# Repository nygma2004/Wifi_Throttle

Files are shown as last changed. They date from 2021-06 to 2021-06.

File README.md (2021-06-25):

# Wifi Throttle
This project is created for my Wifi LokRemote project (https://github.com/nygma2004/Wifi_LokRemote) so I can control my locos using a physical control as opposed to a mobile phone. This project contains a ESP32 Wifi microcontroller which is communicating with the Wifi LokRemote over wifi sending direction, speed, light and sound commands over UDP messages.

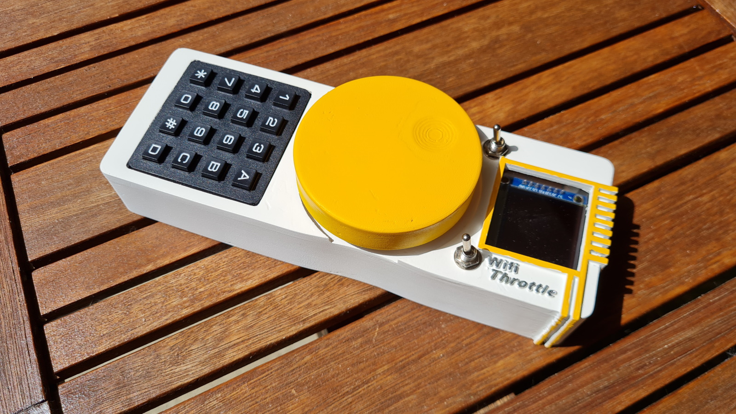
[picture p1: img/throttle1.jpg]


You can also check out my video on how I am using this trhottle for my 7 1/4" gauge ride-on-loco:
Prototype (https://www.youtube.com/watch?v=79uQtgcNUlQ)

Also check the project for the main "receiver" here: https://github.com/nygma2004/Wifi_LokRemote

## Main Features
- Connects to the Wifi network (AP) generated by the LokRemote controller to control the loco from a physical throttle
- Power supply is from a separate 5V power source via the USB port of the ESP32 (e.g. phone battery bank)
- 1.5 inch 128x128 color OLED screen
- Rotary Encoder for speed control
- Ignition switch which can also be wired in parallel with a dead-man switch
- Direction switch
- Keypad to active light functions using buttons 1-3
- Keypad to active sound functions using buttons 4-9
- Vibro motor for tactile feedback
- Acceleration and deceleration is controlled by the LokRemote controller

## Version History / Upcoming Features / Known Issues
V1.0
- Main control implemented: speed, direction control, switching lights, activating sounds
- Mainly designed to work with LokRemote which is configured to work with SaberTooth 3x32 controller, and data feedback such as battery voltage, controller current and temperature readings.
- Wifi connection details hardcoded in the sketch, needs to be worked on
- Create additional screen variants

V1.1
- New feautre: 4 screens created (switch between with A, B, C and D) to show all information / battery voltage / current draw / temperature information
- New feature: Auto reconnect to wifi network when the connection is lost
- Bug: headlights direction does not change the the drive direction changes (this is a bug in the receiver code)

# Hardware
The throttle is build on a custom PCB that you can order from PCBWay: https://www.pcbway.com/project/shareproject/Wifi_Throttle.html.
The components used was mostly purchased from Aliexpress, small components like resistors were purchased from local shop.
- ESP32 WROOM-32 model, on a 30-pin development board: https://www.aliexpress.com/item/32819056304.html (this is a 10 pcs listing)
- Rotary Encoder: from local shop
- 1.5 inch 128x128 RGB OLED screen with SSD1351 driver: http://www.icstation.com/15inch-128x128-oled-display-screen-module-ssd1351-driver-128128-power-p-14400.html
- LR7843 Mosfets: https://www.aliexpress.com/item/32871690649.html
- 4x4 Matrix Keypad
- Pin headers
- 10K resistors
- General signal diode: e.g. 1N4148
- Vibro motor from old mobile phone
- SPDT switch

## Communication Protocol
The Wifi Throttle send UDP messages to LokRemote every 250ms. Each packet is 5 bytes long. The Throttle sends these packets all the time regardless if the ignition switch is on or off. There is a response sent by LokRemote for each message sent by the Throttle. Since these are UDP messages delivery is no guaranteed, but as there are only 2 devices on the network, it is assumed that the loss will be minimal. If the LokRemote does not recieve a message for 2 seconds it will stop the loco.
- Byte 0: direction byte, which is either 0 or 1 depending on the position of the Direction switch
- Byte 1: Speed byte with value from 0 to 255. If the Ignition is switched off, the speed changes to 0
- Byte 2: Lights: Bit7: headlights on/off, Bit6: light 3, Bit5: light 4
- Byte 3: Sound id to be played
- Byte 4: unused
These messages are sent to the LokRemote IP address, and port which is configured in settings.h

The response from LokRemote is 10 bytes, and a reponse is sent every time a message is received from the Throttle. The time between each message is measure by the Throttle and shown on the screen. Response sturcutre is:
- Byte 0-1: Battery voltage * 10 as a 16 bit value where byte 0 is the upper 8 bit, and byte 1 is the lower 8 bit 
- Byte 2-3: Motor 1 current * 10 (format same as battery)
- Byte 4: Motor 1 temperature in celcius
- Byte 5-6: Motor 2 current * 10 (format same as battery)
- Byte 7: Motor 2 temperature in celcius

## Case
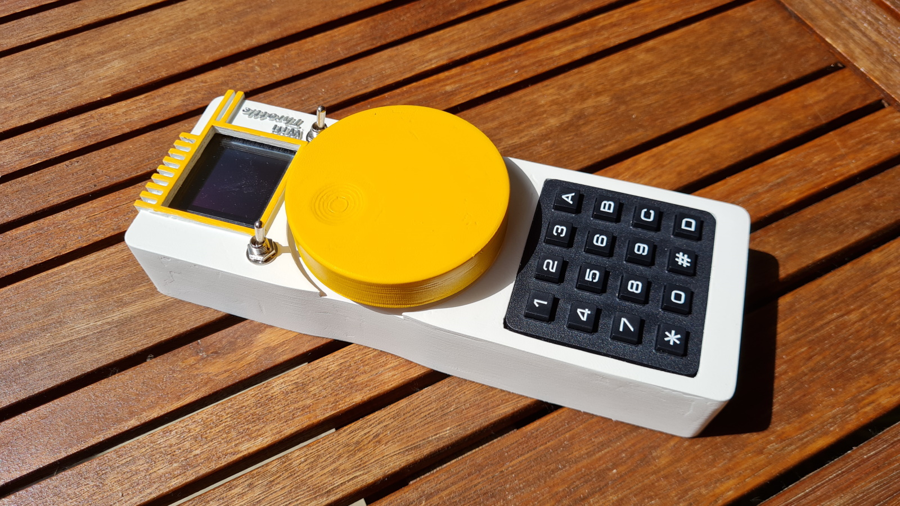
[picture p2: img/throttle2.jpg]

There is a 3D printed case available for this throttle. You can see the 3D files and also the Fusion 360 link in the PCB folder of this project.
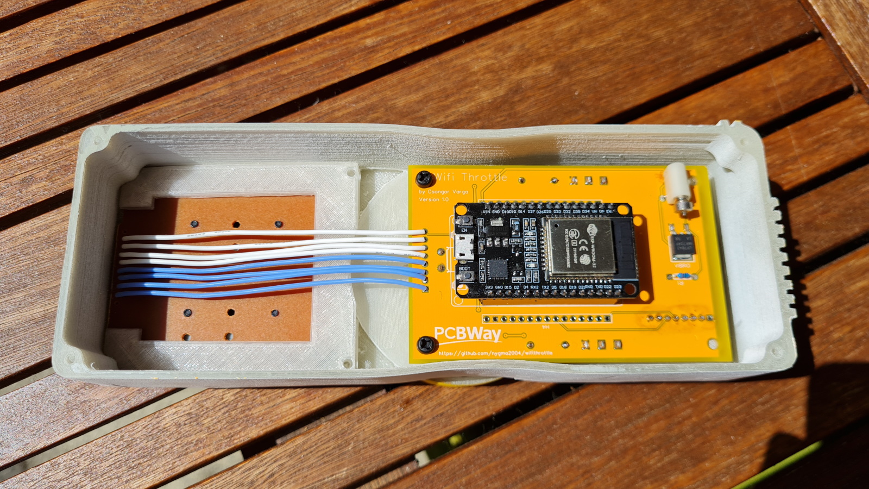
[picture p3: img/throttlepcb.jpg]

The current design is a very early version, I will most probably have to go back and make numerous changes to make it work properly:
- I did not have time to properly battery so it runs off a Blitzwolf BW-P3 power bank and the case is also designed for this rather big battery. I need to work on a smaller and lighter power management for this.
- I made some design errors, the battery is on the top (front) of the controller rather at the bottom (back), the weight distribution feels a bit odd
- There are some measurement errors, the rotary encoder is about 2-3 mm lower than the hole, therefore the hole need some filing
- The recess for the wheel also becomes offset
- Screen is not completely centered between the button, and also not centered within the window. In fact I had to trim the corner of the screen to clear the right switch. This is an issue which also needs fixing on the PCB.
- Cutout for the keypad is very tight, it needed a lot of filing to fit that in place

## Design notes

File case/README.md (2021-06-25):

3d printed case

Fusion 360 project public link: https://a360.co/2SwucIw

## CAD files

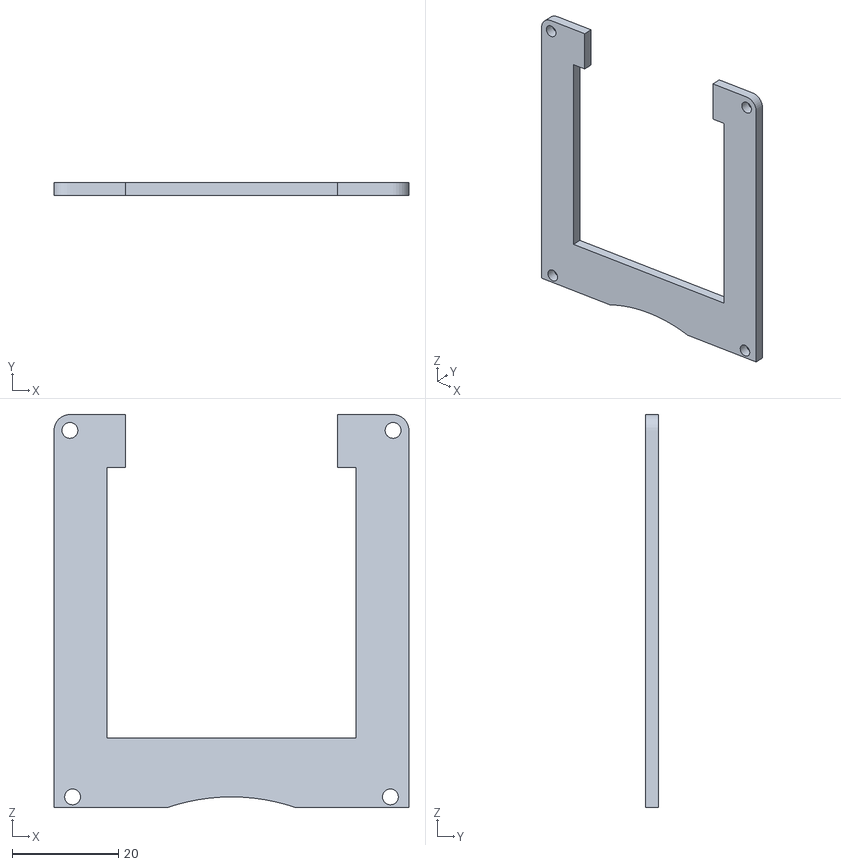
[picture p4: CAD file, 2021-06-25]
case/Keypad bracket.stl
67.0 x 2.50 x 74.1

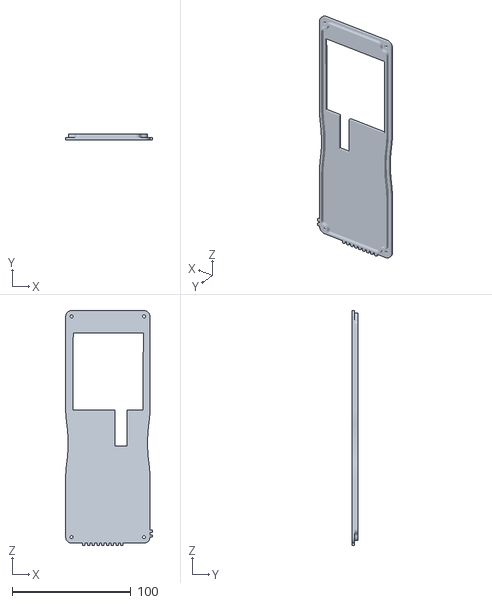
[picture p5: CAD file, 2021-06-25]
case/Bottom Lid.stl
73.0 x 5.00 x 197.7

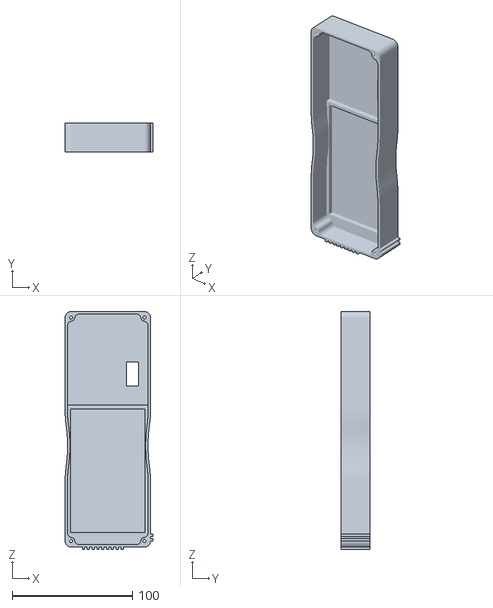
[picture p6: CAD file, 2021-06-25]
case/Battery Holder.stl
73.0 x 24.0 x 197.7

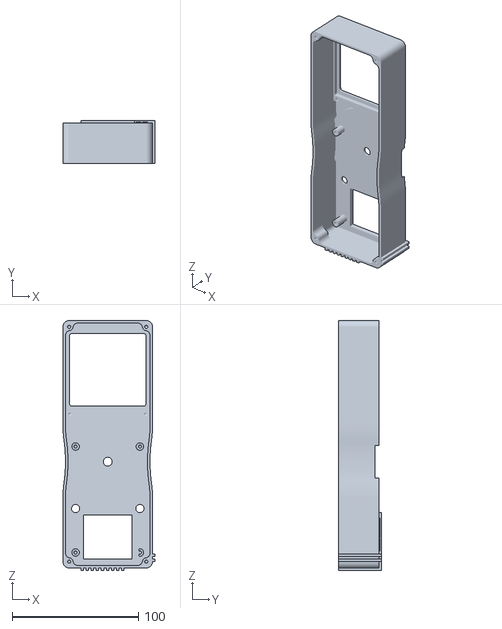
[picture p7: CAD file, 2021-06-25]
case/Body.stl
73.0 x 34.0 x 197.7

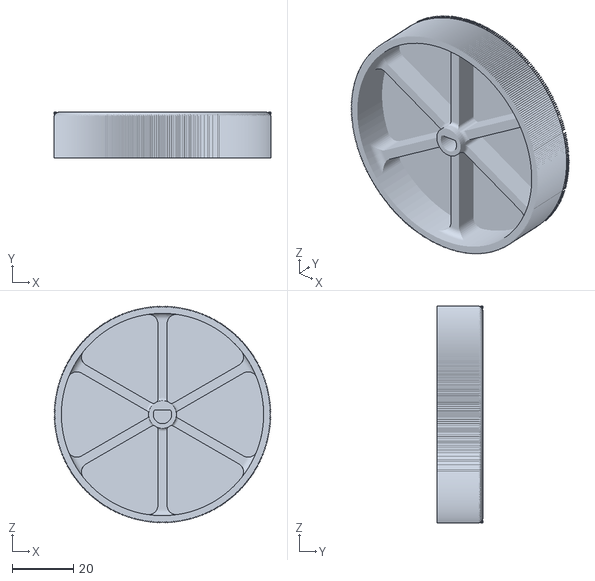
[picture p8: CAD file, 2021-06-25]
case/Wheel.stl
70.8 x 15.0 x 70.8

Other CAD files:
case/Ride on Controller v12.f3d
case/Ride on Controller v13.f3d

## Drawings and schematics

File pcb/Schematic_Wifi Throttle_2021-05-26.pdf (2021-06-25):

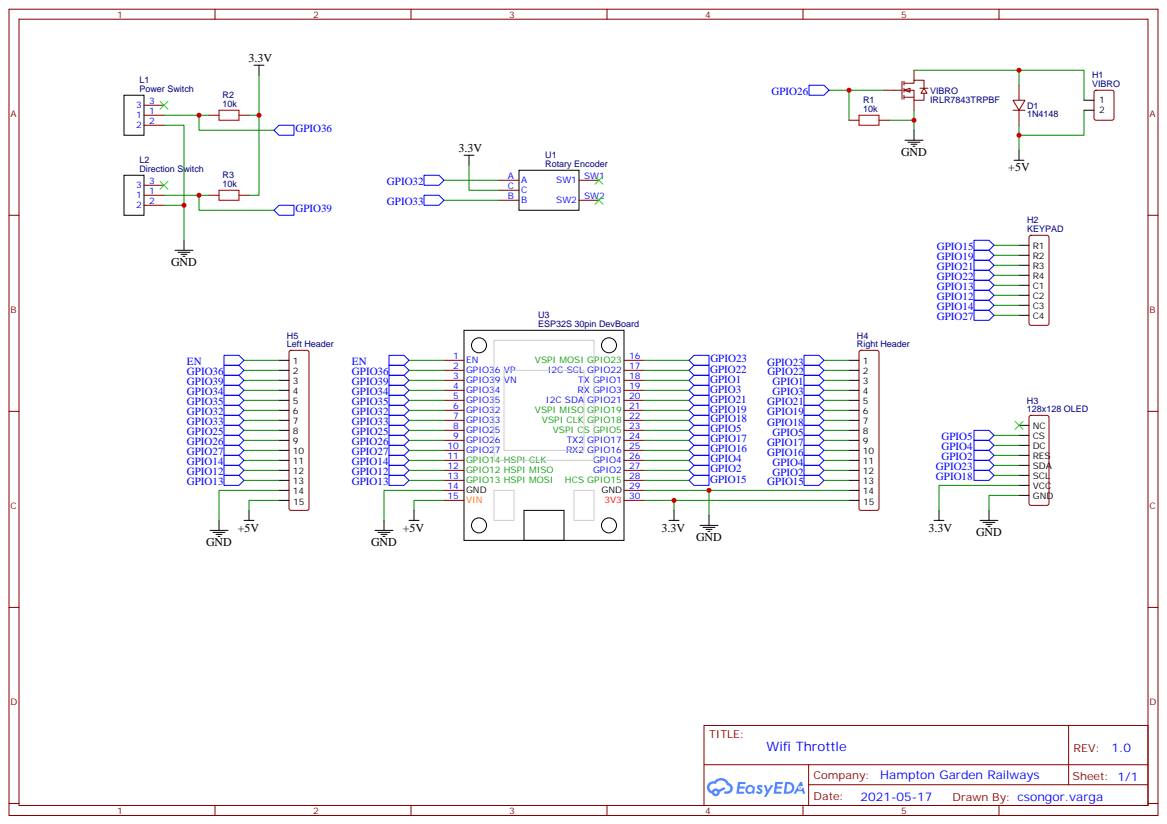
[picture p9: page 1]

3V3 30 GND 29 HCS GPIO15 28 GPIO2 27 GPIO4 26 RX2 GPIO16 25 TX2 GPIO17 24 VSPI CS GPIO5 23 VSPI CLK GPIO18 22 VSPI MISO GPIO19 21 I2C SDA GPIO21 20 RX GPIO3 19 TX GPIO1 18 I2C SCL GPIO22 17 VSPI MOSI GPIO23 16

Company: Hampton Garden Railways

Drawn By: csongor.varga

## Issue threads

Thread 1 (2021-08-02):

Case alignment

kj37075, 2021-08-02:
Excellent job, I think this may work for a similar project that I have, if I can use it I'll definitely share video and notes.
One question, have you or will you edit the case design so the display is corrected? I think that would make it perfect.

Again, great work and thank you for sharing.

nygma2004, 2021-08-04:
I am still thinking about if I want to design a new PCB with some minor changes and design a new case for that or not. The misalignment is on the PCB, not on the case.

Unfortunately I have loads of other project right now, so it will not happen soon.

But I also shared the Fusion 360 file in the case folder in case you want to make changes.

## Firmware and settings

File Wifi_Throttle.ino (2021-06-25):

#include "AiEsp32RotaryEncoder.h"
#include "Arduino.h"
#include "Keypad.h"
#include <SPI.h>
#include <Adafruit_GFX.h>
#include <Adafruit_SSD1351.h>
#include <Fonts/FreeSerifBold18pt7b.h>
#include "icons.h"
#include "globals.h"
#include "settings.h"
#include <jled.h>

#include <WiFi.h>
#include "WiFiUdp.h"
WiFiUDP udp;

Adafruit_SSD1351 display = Adafruit_SSD1351(SCREEN_WIDTH, SCREEN_HEIGHT, &SPI, OLED_CS, OLED_DC,  OLED_RESET);

Keypad keypad = Keypad(makeKeymap(keys), rowPins, colPins, ROWS, COLS);

AiEsp32RotaryEncoder rotaryEncoder = AiEsp32RotaryEncoder(ROTARY_ENCODER_A_PIN, ROTARY_ENCODER_B_PIN, ROTARY_ENCODER_BUTTON_PIN, ROTARY_ENCODER_VCC_PIN, ROTARY_ENCODER_STEPS);

JLed VibroMotor = JLed(VIBROMOTOR).Off();

void rotary_onButtonClick()
{
  static unsigned long lastTimePressed = 0;
  //ignore multiple press in that time milliseconds
  if (millis() - lastTimePressed < 500)
  {
    return;
  }
  lastTimePressed = millis();
  Serial.print("button pressed at ");
  Serial.println(millis());
}

void rotary_loop()
{
  // ignore rotary changes if the power switch is off
  int encodervalue;
  if (power_sw == 0) {
    encodervalue = rotaryEncoder.readEncoder();
  } else {
    return;
  }

  // do not do anything if the value did not change
  if (!rotaryEncoder.encoderChanged())
  {
    return;
  }
  if (!stopped && (encodervalue==0)) {
    stopped = true;
    VibroMotor = JLed(VIBROMOTOR).Blink(500, 100).Repeat(1);
  }
  if (stopped && (encodervalue>0)) {
    stopped = false;
  }

  // simulate the speed tick
  if (!stopped && (encodervalue>0) && speedtick) {
    VibroMotor = JLed(VIBROMOTOR).Blink(25,20*(255-encodervalue)).Forever();
  }
  Serial.print("Value: ");
  Serial.println(encodervalue);
  UpdateDisplay(OLED_UPDATE_SPEED);

}

void DisplaySplashScreen() {
  for (int x=0; x<128; x++) {
    for (int y=0; y<128; y++) {
      display.drawPixel(x, y, splash[y*128+x]);
    }
  }
}

void DrawBackgroundScreen() {
  for (int x=0; x<128; x++) {
    for (int y=0; y<128; y++) {
      display.drawPixel(x, y, background[y*128+x]);
    }
  }
}

void UpdateDisplay(byte UpdateReason) {

  //Serial.print("Screen update: ");
  //Serial.println(UpdateReason);
  // RSSI update

  display.setFont();
  if (millis()-lastRSSI>500) {
    display.setTextSize(1);
    int rssi = WiFi.RSSI();
    display.drawBitmap(OLED_WIFI_X, OLED_WIFI_Y, icon_blank, 16, 16, OLED_Color_Black);
    if (rssi<-80) {
      display.drawBitmap(OLED_WIFI_X, OLED_WIFI_Y, icon_wifi[0], 16, 16, OLED_Color_Red);
      display.setTextColor(OLED_Color_Red);
    } else {
       if (rssi<-70) {
          display.drawBitmap(OLED_WIFI_X, OLED_WIFI_Y, icon_wifi[1], 16, 16, OLED_Color_Yellow); 
          display.setTextColor(OLED_Color_Yellow);
       } else {
          if (rssi<-60) {
            display.drawBitmap(OLED_WIFI_X, OLED_WIFI_Y, icon_wifi[2], 16, 16, OLED_Color_White); 
            display.setTextColor(OLED_Color_White);
          } else {
            display.drawBitmap(OLED_WIFI_X, OLED_WIFI_Y, icon_wifi[3], 16, 16, OLED_Color_White); 
            display.setTextColor(OLED_Color_White);
          }
       }
    }
    display.fillRect(OLED_RSSI_X,OLED_RSSI_Y, OLED_SMALLFONT_W*3, OLED_SMALLFONT_H, OLED_Color_Black);
    display.setCursor(OLED_RSSI_X,OLED_RSSI_Y);
    display.println(rssi);
    lastRSSI = millis();
  }

  // Speed update
  if (UpdateReason & OLED_UPDATE_SPEED) {
    int encoder = rotaryEncoder.readEncoder();
    display.fillTriangle(OLED_SPEED_X,OLED_SPEED_Y, OLED_SPEED_X+OLED_SPEED_W,OLED_SPEED_Y, OLED_SPEED_X+OLED_SPEED_W,OLED_SPEED_Y-OLED_SPEED_H,OLED_Color_Black);
    display.drawTriangle(OLED_SPEED_X,OLED_SPEED_Y, OLED_SPEED_X+OLED_SPEED_W,OLED_SPEED_Y, OLED_SPEED_X+OLED_SPEED_W,OLED_SPEED_Y-OLED_SPEED_H,OLED_Color_Yellow);
    display.fillTriangle(OLED_SPEED_X,OLED_SPEED_Y, OLED_SPEED_X+(int)(OLED_SPEED_W*encoder/255),OLED_SPEED_Y, OLED_SPEED_X+(int)(OLED_SPEED_W*encoder/255),OLED_SPEED_Y-(int)(OLED_SPEED_H*encoder/255),OLED_Color_Yellow);
    
    display.setTextColor(OLED_Color_White);
    display.setCursor(OLED_ENCODER_VAL_X,OLED_ENCODER_VAL_Y);
    display.fillRect(OLED_ENCODER_VAL_X,OLED_ENCODER_VAL_Y, OLED_SMALLFONT_W*3, OLED_SMALLFONT_H, OLED_Color_Black);
    display.print(rotaryEncoder.readEncoder());
  }

  // Direction
  if (UpdateReason & OLED_UPDATE_DIRECTION) {
    //Serial.println("Direction");
    if (power_sw == 1) {
      // both arrow red
      //Serial.println("Red arrows");
      display.drawBitmap(OLED_LEFTDIR_X, OLED_LEFTDIR_Y, dir_left, 15, 80, OLED_Color_Red);
      display.drawBitmap(OLED_RIGHTDIR_X, OLED_RIGHTDIR_Y, dir_right, 15, 80, OLED_Color_Red);
    } else {
      if (direction_sw == 0) {
        // forward
        //Serial.println("Right green");
        display.drawBitmap(OLED_LEFTDIR_X, OLED_LEFTDIR_Y, dir_left, 15, 80, OLED_Color_Black);
        display.drawBitmap(OLED_RIGHTDIR_X, OLED_RIGHTDIR_Y, dir_right, 15, 80, OLED_Color_Green);
      } else {
        // reverse
        //Serial.println("Left green");
        display.drawBitmap(OLED_LEFTDIR_X, OLED_LEFTDIR_Y, dir_left, 15, 80, OLED_Color_Green);
        display.drawBitmap(OLED_RIGHTDIR_X, OLED_RIGHTDIR_Y, dir_right, 15, 80, OLED_Color_Black);
      }
    }
    
  }

  // Sabertooth info update
  if (UpdateReason & OLED_UPDATE_SABER) {
    if (millis()-lastSaber>500) {

      if (displaymode==0) {
        // All Sabertooth data on the screen
        display.fillRect(OLED_ALL_BAT_X,OLED_ALL_BAT_Y, OLED_SMALLFONT_W*OLED_ALL_BAT_W, OLED_SMALLFONT_H, OLED_Color_Black);
        display.setTextColor(OLED_Color_White);
        display.setCursor(OLED_ALL_BAT_X,OLED_ALL_BAT_Y);
        display.print("B: ");
        display.print(battery);
        display.print("V");
  
        display.fillRect(OLED_ALL_M1_X,OLED_ALL_M1_Y, OLED_SMALLFONT_W*OLED_ALL_M1_W, OLED_SMALLFONT_H, OLED_Color_Black);
        display.setCursor(OLED_ALL_M1_X,OLED_ALL_M1_Y);
        display.print("M1: ");
        display.print(m1current);
        display.print("A, ");
        display.print(m1temp);
        display.print("C");
        
        display.fillRect(OLED_ALL_M2_X,OLED_ALL_M2_Y, OLED_SMALLFONT_W*OLED_ALL_M2_W, OLED_SMALLFONT_H, OLED_Color_Black);
        display.setCursor(OLED_ALL_M2_X,OLED_ALL_M2_Y);
        display.print("M2: ");
        display.print(m2current);
        display.print("A, ");
        display.print(m2temp);
        display.print("C");
      }
      if (displaymode==1) {
        // Battery information
        display.setTextColor(OLED_Color_White);
        display.setCursor(OLED_BATTEXT_X,OLED_BATTEXT_Y);
        display.print("Battery");
        display.setFont(&FreeSerifBold18pt7b);
        display.fillRect(OLED_BAT_X,OLED_BAT_Y, OLED_LARGEFONT_W*OLED_BAT_W, OLED_LARGEFONT_H, OLED_Color_Black);
        display.setTextColor(OLED_Color_White);
        display.setCursor(OLED_BAT_X,OLED_BAT_Y+OLED_LARGEFONT_H);
        display.print(battery);
        display.setFont();
        display.fillRect(OLED_BATMIN_X,OLED_BATMIN_Y, OLED_SMALLFONT_W*OLED_BAT_W, OLED_SMALLFONT_H, OLED_Color_Black);
        display.setCursor(OLED_BATMIN_X,OLED_BATMIN_Y);
        display.print(battmin);
      }
      if (displaymode==2) {
        // Current information
        display.setTextColor(OLED_Color_White);
        display.setCursor(OLED_CURTEXT_X,OLED_CURTEXT_Y);
        display.print("Current");
        display.setFont(&FreeSerifBold18pt7b);
        display.fillRect(OLED_CURM1_X,OLED_CURM1_Y, OLED_LARGEFONT_W*OLED_CUR_W, OLED_LARGEFONT_H, OLED_Color_Black);
        display.setTextColor(OLED_Color_White);
        display.setCursor(OLED_CURM1_X,OLED_CURM1_Y+OLED_LARGEFONT_H);
        display.print(m1current);
        display.fillRect(OLED_CURM2_X,OLED_CURM2_Y, OLED_LARGEFONT_W*OLED_CUR_W, OLED_LARGEFONT_H, OLED_Color_Black);
        display.setCursor(OLED_CURM2_X,OLED_CURM2_Y+OLED_LARGEFONT_H);
        display.print(m2current);
        display.setFont();
      }
      if (displaymode==3) {
        // Temperature information
        display.setTextColor(OLED_Color_White);
        display.setCursor(OLED_TEMPTEXT_X,OLED_TEMPTEXT_Y);
        display.print("Temperature");
        display.setFont(&FreeSerifBold18pt7b);
        display.fillRect(OLED_TEMPM1_X,OLED_TEMPM1_Y, OLED_LARGEFONT_W*OLED_TEMP_W, OLED_LARGEFONT_H, OLED_Color_Black);
        display.setTextColor(OLED_Color_White);
        display.setCursor(OLED_TEMPM1_X,OLED_TEMPM1_Y+OLED_LARGEFONT_H);
        display.print(m1temp);
        display.print("C");
        display.fillRect(OLED_TEMPM2_X,OLED_TEMPM2_Y, OLED_LARGEFONT_W*OLED_TEMP_W, OLED_LARGEFONT_H, OLED_Color_Black);
        display.setCursor(OLED_TEMPM2_X,OLED_TEMPM2_Y+OLED_LARGEFONT_H);
        display.print(m2temp);
        display.print("C");
        display.setFont();
      }
      
      lastSaber = millis();
    }
  }

  // Controller response interval
  if (UpdateReason & OLED_UPDATE_INTERVAL) {
    if (millis()-lastResponseUpdate>500) {

      String text = String(lastResponseInterval);
      if (lastResponseInterval>1000) {
        display.setTextColor(OLED_Color_Red);
        text = "----";
      } else {
        if (lastResponseInterval>500) {
          display.setTextColor(OLED_Color_Yellow);
        } else {
          display.setTextColor(OLED_Color_White);
        }
      }

      display.setCursor(OLED_INTERVAL_X,OLED_INTERVAL_Y);
      display.fillRect(OLED_INTERVAL_X,OLED_INTERVAL_Y, OLED_SMALLFONT_W*4, OLED_SMALLFONT_H, OLED_Color_Black);
      display.print(text);

      lastResponseUpdate = millis();
    }
  }  
  
}

void setup()
{
  Serial.begin(115200);
  delay(100);
  Serial.println();
  Serial.println("Rotary Encoder test");

    display.begin();
    display.setFont();
    display.fillScreen(OLED_Backround_Color);
    DisplaySplashScreen();
    display.setTextColor(OLED_Text_Color);
    display.setTextSize(1);


  pinMode(SW_POWER, INPUT);
  pinMode(SW_DIRECTION, INPUT);
  pinMode(VIBROMOTOR, OUTPUT);

  //we must initialize rotary encoder
  rotaryEncoder.begin();

  rotaryEncoder.setup(
    [] { rotaryEncoder.readEncoder_ISR(); },
    [] { rotary_onButtonClick(); });

  //set boundaries and if values should cycle or not
  //in this example we will set possible values between 0 and 1000;
  bool circleValues = false;
  rotaryEncoder.setBoundaries(0, 255, circleValues); //minValue, maxValue, circleValues true|false (when max go to min and vice versa)

  /*Rotary acceleration introduced 25.2.2021.
   * in case range to select is huge, for example - select a value between 0 and 1000 and we want 785
   * without accelerateion you need long time to get to that number
   * Using acceleration, faster you turn, faster will the value raise.
   * For fine tuning slow down.
   */
  //rotaryEncoder.disableAcceleration(); //acceleration is now enabled by default - disable if you dont need it
  rotaryEncoder.setAcceleration(100); //or set the value - larger number = more accelearation; 0 or 1 means disabled acceleration

    Serial.print("Connecting to wifi network");
  
    WiFi.begin(ssid, password);
  
    while (WiFi.status() != WL_CONNECTED) {
      delay(500);
      Serial.print(".");
    }

    Serial.println("");
    Serial.print("Connected to ");
    Serial.println(ssid);
    Serial.print("IP address: ");
    Serial.println(WiFi.localIP());
    Serial.print("Signal [RSSI]: ");
    Serial.println(WiFi.RSSI());

  if (udp.begin(4445)) {
    Serial.print("UDP running at IP: ");
    Serial.print(WiFi.localIP());
    Serial.println(" port: 4445");
  }
  VibroMotor = JLed(VIBROMOTOR).Blink(50, 50).Repeat(3);

  DrawBackgroundScreen();
  UpdateDisplay(OLED_UPDATE_ALL);
}

void loop()
{
  //in loop call your custom function which will process rotary encoder values
  rotary_loop();

  VibroMotor.Update();

  if (millis() - lastWifiCheck >= 250) {
    // reconnect to the wifi network if connection is lost
    if (WiFi.status() != WL_CONNECTED) {
      Serial.println("Reconnecting to wifi...");
      WiFi.reconnect();
    }
    lastWifiCheck = millis();
  }

  char key = keypad.getKey();

  if (key) {
    Serial.print("Key pressed: ");
    Serial.println(key);
    switch (key) {
      case '1':
        lightState = !lightState;
        Serial.print("Light 1: ");
        Serial.println(lightState);
        break;
      case '2':
        light3State = !light3State;
        break;
      case '3':
        light4State = !light4State;
        break;
      case '4':
        soundid = 1;
        lastSound = millis();
        break;
      case '5':
        soundid = 2;
        lastSound = millis();
        break;
      case '6':
        soundid = 3;
        lastSound = millis();
        break;
      case '7':
        soundid = 4;
        lastSound = millis();
        break;
      case '8':
        soundid = 5;
        lastSound = millis();
        break;
      case '9':
        soundid = 6;
        lastSound = millis();
        break;
      case 'A':
        displaymode = 0;
        display.fillRect(OLED_CLEAR_X,OLED_CLEAR_Y, OLED_CLEAR_W, OLED_CLEAR_H, OLED_Color_Black);
        break;
      case 'B':
        displaymode = 1;
        display.fillRect(OLED_CLEAR_X,OLED_CLEAR_Y, OLED_CLEAR_W, OLED_CLEAR_H, OLED_Color_Black);
        break;
      case 'C':
        displaymode = 2;
        display.fillRect(OLED_CLEAR_X,OLED_CLEAR_Y, OLED_CLEAR_W, OLED_CLEAR_H, OLED_Color_Black);
        break;
      case 'D':
        displaymode = 3;
        display.fillRect(OLED_CLEAR_X,OLED_CLEAR_Y, OLED_CLEAR_W, OLED_CLEAR_H, OLED_Color_Black);
        break;
      case '#':
        speedtick = !speedtick;
        if (!speedtick) VibroMotor = JLed(VIBROMOTOR).Off();
        break;

    }
  } else {
    if (millis()-lastSound > 500) {
      soundid = 0;
    }
  }

  if (millis()-lastUDP > 250) {
    int direction_temp = digitalRead(SW_DIRECTION);
    if (direction_temp!=direction_sw) {
      direction_sw = direction_temp;
      UpdateDisplay(OLED_UPDATE_DIRECTION);
    }
    int power_temp = digitalRead(SW_POWER);
    if (power_temp!=power_sw) {
      power_sw = power_temp;
      UpdateDisplay(OLED_UPDATE_DIRECTION);
    }
    ThrottleBuffer[0] = direction_sw ? 1 : 0;
    if (power_sw == 0) {
      ThrottleBuffer[1] = rotaryEncoder.readEncoder();
    } else {
      ThrottleBuffer[1] = 0;
      rotaryEncoder.setEncoderValue(0);
      if (!stopped) {
        VibroMotor = JLed(VIBROMOTOR).Blink(500, 100).Repeat(1);
        stopped = true;
      }
      UpdateDisplay(OLED_UPDATE_SPEED + OLED_UPDATE_DIRECTION);
    }
    ThrottleBuffer[2] = 0;
    ThrottleBuffer[2] += lightState << 7;
    ThrottleBuffer[2] += light3State << 6;
    ThrottleBuffer[2] += light4State << 5;
    ThrottleBuffer[3] = soundid;
    ThrottleBuffer[4] = 0;
    udp.beginPacket(udpAddress,udpPort);
    udp.write(ThrottleBuffer, 5);
    udp.endPacket();
    //Serial.print("UDP packet sent : ");
    //Serial.print(ThrottleBuffer[0]);
    //Serial.print(", ");
    //Serial.print(ThrottleBuffer[1]);
    //Serial.print(", ");
    //Serial.print(ThrottleBuffer[2]);
    //Serial.print(", ");
    //Serial.print(ThrottleBuffer[3]);
    //Serial.print(", ");
    //Serial.print(ThrottleBuffer[4]);
    //Serial.println(" <");

    lastUDP=millis();
  }


  int packetSize = udp.parsePacket();
  if (packetSize) {
    //Serial.print("Received packet of size ");
    //Serial.println(packetSize);
    //Serial.print("From ");
    //IPAddress remoteIp = udp.remoteIP();
    //Serial.print(remoteIp);
    //Serial.print(", port ");
    //Serial.println(udp.remotePort());
    // read the packet into packetBufffer
    int len = udp.read(packetBuffer, 255);
    if (len > 0) {
      packetBuffer[len] = 0;
    }
    //Serial.println("Contents:");
    //Serial.println(packetBuffer);
    battery = ((float)packetBuffer[0]*256+packetBuffer[1])/10;
    if (battery<battmin) {
      battmin = battery;
    }
    m1current = ((float)packetBuffer[2]*256+packetBuffer[3])/10;
    m1temp = packetBuffer[4];
    m2current = ((float)packetBuffer[5]*256+packetBuffer[6])/10;
    m2temp = packetBuffer[7];
    lastResponseInterval=millis()-lastResponse;
    lastResponse=millis();
    UpdateDisplay(OLED_UPDATE_SABER+OLED_UPDATE_INTERVAL);
  }

  if (millis()-lastResponse > 500) {
    lastResponseInterval=millis()-lastResponse;  
    UpdateDisplay(OLED_UPDATE_INTERVAL);
  }


}

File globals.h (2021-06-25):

#define OLED_WIFI_X 0
#define OLED_WIFI_Y 0

#define OLED_RSSI_X 18
#define OLED_RSSI_Y 5

#define OLED_ENCODER_VAL_X 25
#define OLED_ENCODER_VAL_Y 110

#define OLED_SPEED_X 10
#define OLED_SPEED_Y 126
#define OLED_SPEED_W 108
#define OLED_SPEED_H 25

#define OLED_LEFTDIR_X 0
#define OLED_LEFTDIR_Y 20
#define OLED_RIGHTDIR_X 113
#define OLED_RIGHTDIR_Y 20

#define OLED_UPDATE_ALL 0xFF
#define OLED_UPDATE_SPEED     0b00000001
#define OLED_UPDATE_SABER     0b00000010
#define OLED_UPDATE_DIRECTION 0b00000100
#define OLED_UPDATE_INTERVAL  0b00001000

#define OLED_SMALLFONT_W 6
#define OLED_SMALLFONT_H 8
#define OLED_LARGEFONT_W 22
#define OLED_LARGEFONT_H 25

#define OLED_INTERVAL_X 45
#define OLED_INTERVAL_Y 5

#define OLED_ALL_BAT_X 20
#define OLED_ALL_BAT_Y 40
#define OLED_ALL_BAT_W 9

#define OLED_CURTEXT_X 40
#define OLED_CURTEXT_Y 28
#define OLED_CURM1_X 20
#define OLED_CURM1_Y 38
#define OLED_CUR_W 4
#define OLED_CURM2_X 20
#define OLED_CURM2_Y 70

#define OLED_TEMPTEXT_X 30
#define OLED_TEMPTEXT_Y 28
#define OLED_TEMPM1_X 20
#define OLED_TEMPM1_Y 38
#define OLED_TEMP_W 4
#define OLED_TEMPM2_X 20
#define OLED_TEMPM2_Y 70

#define OLED_BATTEXT_X 40
#define OLED_BATTEXT_Y 35
#define OLED_BAT_X 20
#define OLED_BAT_Y 45
#define OLED_BAT_W 3
#define OLED_BATMIN_X 45
#define OLED_BATMIN_Y 85

#define OLED_ALL_M1_X 20
#define OLED_ALL_M1_Y 55
#define OLED_ALL_M1_W 14

#define OLED_ALL_M2_X 20
#define OLED_ALL_M2_Y 70
#define OLED_ALL_M2_W 14

#define OLED_CLEAR_X 20
#define OLED_CLEAR_Y 25
#define OLED_CLEAR_W 92
#define OLED_CLEAR_H 78

#define SW_POWER 36
#define SW_DIRECTION 39
#define VIBROMOTOR 26

// Screen dimensions
#define SCREEN_WIDTH  128
#define SCREEN_HEIGHT 128 
#define OLED_MOSI  23  // SDA
#define OLED_CLK   18  // SCL
#define OLED_DC    4
#define OLED_CS    5
#define OLED_RESET 2

// SSD1331 color definitions
const uint16_t  OLED_Color_Black        = 0x0000;
const uint16_t  OLED_Color_Blue         = 0x001F;
const uint16_t  OLED_Color_Red          = 0xF800;
const uint16_t  OLED_Color_Green        = 0x07E0;
const uint16_t  OLED_Color_Cyan         = 0x07FF;
const uint16_t  OLED_Color_Magenta      = 0xF81F;
const uint16_t  OLED_Color_Yellow       = 0xFFE0;
const uint16_t  OLED_Color_White        = 0xFFFF;

// The colors we actually want to use
uint16_t        OLED_Text_Color         = OLED_Color_Black;
uint16_t        OLED_Backround_Color    = OLED_Color_Blue;


const byte ROWS = 4; //four rows
const byte COLS = 4; //four columns

char keys[ROWS][COLS] = {
  {'1','2','3','A'},
  {'4','5','6','B'},
  {'7','8','9','C'},
  {'*','0','#','D'}
};
byte colPins[ROWS] = {15, 19, 21, 22}; 
byte rowPins[COLS] = {13, 12, 14, 27};

/*
connecting Rotary encoder
Rotary encoder side    MICROCONTROLLER side  
-------------------    ---------------------------------------------------------------------
CLK (A pin)            any microcontroler intput pin with interrupt -> in this example pin 32
DT (B pin)             any microcontroler intput pin with interrupt -> in this example pin 21
SW (button pin)        any microcontroler intput pin with interrupt -> in this example pin 25
GND - to microcontroler GND
VCC                    microcontroler VCC (then set ROTARY_ENCODER_VCC_PIN -1) 
***OR in case VCC pin is not free you can cheat and connect:***
VCC                    any microcontroler output pin - but set also ROTARY_ENCODER_VCC_PIN 25 
                        in this example pin 25
*/
#define ROTARY_ENCODER_A_PIN 32
#define ROTARY_ENCODER_B_PIN 33
#define ROTARY_ENCODER_BUTTON_PIN 25
#define ROTARY_ENCODER_VCC_PIN -1 /* 27 put -1 of Rotary encoder Vcc is connected directly to 3,3V; else you can use declared output pin for powering rotary encoder */

//depending on your encoder - try 1,2 or 4 to get expected behaviour
//#define ROTARY_ENCODER_STEPS 1
//#define ROTARY_ENCODER_STEPS 2
#define ROTARY_ENCODER_STEPS 4

unsigned int lastUDP, lastSound;
char packetBuffer[255]; //buffer to hold incoming packet
byte ThrottleBuffer[5] = {0x00, 0x00, 0x00, 0x00, 0x00 };


int motorspeed, m1temp, m2temp, soundid;
bool lightState, light3State, light4State, speedtick;
float battery, m1current, m2current;
int displaymode = 0;
float battmin = 1000.0;

unsigned int lastRSSI, lastSaber, lastResponse, lastResponseInterval, lastResponseUpdate, lastWifiCheck;
int direction_sw, power_sw;
bool stopped;
